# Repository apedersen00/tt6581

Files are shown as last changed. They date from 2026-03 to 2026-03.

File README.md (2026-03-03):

  

# TT6581

Inspired by the legendary MOS6581 Sound Interface Device (SID) chip used in retro computers such as the Commodore 64, the _Tiny Tapeout_ 6581 (TT6581) is a original digital interpretation supporting nearly the entire original MOS6581 feature set, implemented in 2x2 tiles for Tiny Tapeout.

For a detailed write-up, see the [project page](https://andreaspedersen.com/projects/tt6581/).

As a demonstration, here are two songs that **are produced by RTL testbenches**:

1. **Port of _Monty on the Run_ by Rob Hubbard** (`sim_tt6581_player.cpp`)

https://github.com/user-attachments/assets/aede3a49-307a-4b56-abea-9a842e0d1250

2. **10-second Nocturne demonstrating the filter** (`sim_tt6581.cpp`)

https://github.com/user-attachments/assets/fff6d938-7d75-444d-9261-1e6ea31e3630

## Features

- Full control through a Serial-Peripheral Interface (SPI).
- Three independently synthesized voices.
- Four supported waveform types (triangle, sawtooth, square and noise).
- Attack, decay, sustain, release (ADSR) envelope shaping.
- Chamberlin State-Variable Filter (SVF) for low-pass, high-pass, band-pass and band-reject.
- Second-order Delta-Sigma DAC.

## Architecture

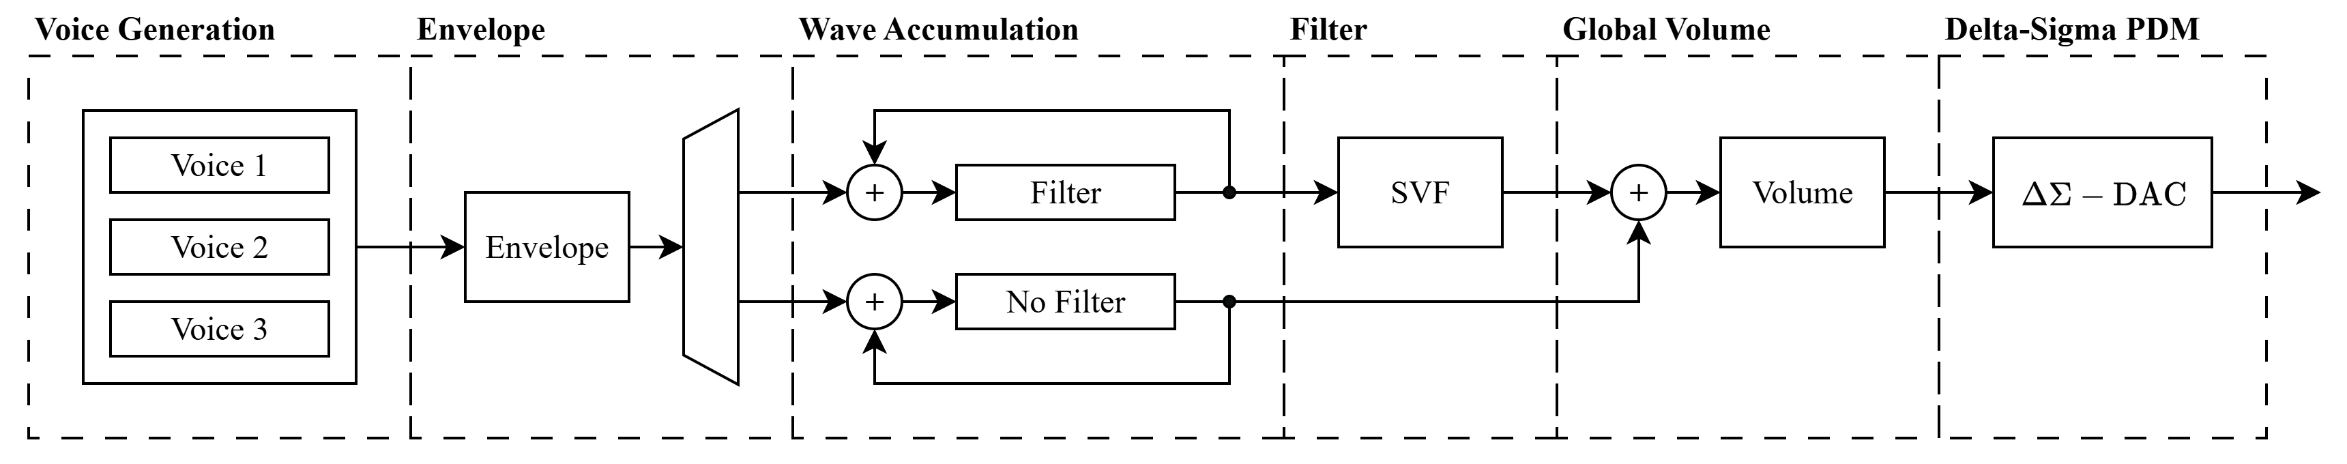
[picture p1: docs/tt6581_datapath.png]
TT6581 Architecture


The diagram above shows the datapath in the TT6581. A tick generator triggers the generation of a single audio sample at 50 kHz.

1. **Voice Generation:** One 10-bit voice at a time is generated. Internal phase registers keep track of each voice's state while inactive. The frequency and waveform type are set by the programmed values in the register file. Supported waveforms are triangle, sawtooth, pulse or noise.

2. **Envelope:** An ADSR envelope generator produces an 8-bit amplitude value per voice. The envelope is applied to each voice by multiplication.

3. **Wave Accumulation:** The three voices are accumulated (mixed) by addition. Depending on the filter enable bit of each voice, they are accumulated in one of two registers: one that will be passed through the SVF, or one that will bypass it.

4. **Filter:** A Chamberlin State-Variable Filter (SVF) processes the filter accumulator. It supports low-pass, high-pass, band-pass and band-reject modes with tuneable frequency cutoff and resonance (Q).

5. **Global Volume:** The SVF output is summed with the bypass accumulator. A global 8-bit volume is applied by multiplication resulting in the final mix.

6. **Delta-Sigma PDM:** An error-feedback Delta-Sigma modulator converts the final mix to 1-bit PDM output at 10 MHz (OSR = 200).

To fit the strict 2x2 tiles area requirement, the entire synthesis is time-multiplexed meaning most modules are _finite state machines_. A single 24x16 multiplier is shared for all modules. The 50 kHz sample tick wakes up a master controller (FSM) that then initiates the synthesis of a single sample.

## Pin Mapping

The TT6581 uses the bidirectional IO pins for SPI and a single dedicated output for the PDM audio signal. All dedicated inputs are unused.

| Pin | Direction | Function |
| --- | --- | --- |
| `uio[0]` | Input | SPI Chip Select (active low) |
| `uio[1]` | Input | SPI MOSI |
| `uio[2]` | Output | SPI MISO |
| `uio[3]` | Input | SPI SCLK |
| `uio[4:7]` | - | Unused |
| `uo[0]` | Output | PDM audio output |
| `uo[1:7]`  | - | Unused |
| `ui[0:7]`  | - | Unused |

The PDM output should be passed through a 4th order Bessel filter for the best reconstruction of the analog waveform.

## Quick Start

The TT6581 is programmed in much the same way as the original MOS6581. The register layout mirrors the original SID, three voice channels followed by filter and volume registers and the same ADSR, waveform selection and filter concepts apply. The main differences are:

- Registers are accessed through an SPI interface.
- The filter coefficients are pre-calculated and written directly as fixed-point values, rather than the raw 11-bit FC value used by the MOS6581.

Keeping the changes in mind, the original MOS6581 datasheet is a good reference for how to use the TT6581.

### SPI Protocol

The SPI interface uses CPOL=0, CPHA=0 (data sampled on the rising edge of SCLK). Each transaction is a 16-bit frame while CS is held low:

| Bit | 15 | 14:8 | 7:0 |
| ----- | --- | --- | --- |
| Field | R/W | Address \[6:0\] | Data \[7:0\] |

- **Bit 15** = `1` for write, `0` for read.
- **Bits 14:8** = 7-bit register address.
- **Bits 7:0** = write data.

Data is transmitted MSB first.

### Playing a tone

1. **Set volume:** Write `0xFF` to register `VOLUME` for max volume.
2. **Set frequency:** Compute the 16-bit frequency control word and write it to `FREQ_LO` / `FREQ_HI`.
3. **Set ADSR:** Write attack/decay to `AD` and sustain/release to `SR`.
4. **Select waveform and gate on:** Write the CONTROL register with the desired waveform bit and `GATE=1`.

For example, to play a 440 Hz sawtooth on Voice 0 with instant attack and full sustain:

```
SPI Write: addr=0x1A, data=0xFF    # Volume = max
SPI Write: addr=0x00, data=0x05    # FREQ_LO = 0x05  (FCW for 440 Hz = 0x1205)
SPI Write: addr=0x01, data=0x12    # FREQ_HI = 0x12
SPI Write: addr=0x05, data=0x00    # AD = 0x00 (attack=0, decay=0)
SPI Write: addr=0x06, data=0xF0    # SR = 0xF0 (sustain=15, release=0)
SPI Write: addr=0x04, data=0x21    # CONTROL = sawtooth + gate on
```

To release the note, write CONTROL again with `GATE=0`:

```
SPI Write: addr=0x04, data=0x20    # CONTROL = sawtooth + gate off
```

### Formulas

**Frequency Control Word (FCW):**

$$
FCW = \frac{f_{\text{desired}} \cdot 2^{19}}{F_s}
$$

where $F_s = 50$ kHz (sample rate). The 16-bit FCW is split across `FREQ_LO` (bits 7:0) and `FREQ_HI` (bits 15:8).

The maximum representable voice frequency is limited by the 16-bit FCW:

$$
f_{\max} = \frac{65535 \cdot F_s}{2^{19}} \approx 6250 \text{ Hz}
$$

**Filter Cutoff Coefficient** (Q1.15 signed):

$$
\text{FCC} = \left[ 2 \cdot \sin \left(\frac{\pi \cdot f_c}{F_s}\right) \cdot 32768 \right]
$$

where $f_c$ is the desired cutoff frequency in Hz. The 16-bit result is split across `F_LO` and `F_HI`.

**Filter Damping Coefficient** (Q4.12 signed):

$$
\text{FDC} = \left[ \frac{1}{Q} \cdot 4096 \right]
$$

where $Q$ is the desired resonance. The 16-bit result is split across `Q_LO` and `Q_HI`.

## Register Map

The TT6581 has a 7-bit address space and 26 8-bit registers. Three identical voice register groups are followed by a filter/volume group.

The full register map is described in `regs.yaml`.

### Voice Registers

Each voice occupies 7 consecutive 8-bit registers. Voice 0 starts at `0x00`, Voice 1 at `0x07`, and Voice 2 at `0x0E`.

| Offset | Name | Bits | Description |
| --- | --- | ---- | --- |
| 0x00 | FREQ_LO | 7:0  | Frequency control word - low byte  |
| 0x01 | FREQ_HI | 7:0  | Frequency control word - high byte |
| 0x02 | PW_LO | 7:0  | Pulse width - low byte |
| 0x03 | PW_HI | 3:0  | Pulse width - high byte |
| 0x04 | CONTROL | 7:0  | Waveform select and voice control  |
| 0x05 | AD | 7:0  | Attack (7:4) / Decay (3:0) |
| 0x06 | SR | 7:0  | Sustain (7:4) / Release (3:0) |

**CONTROL register bit fields:**

| Bit | Name | Description |
| --- | --- | --- |
| 7 | NOISE | Select noise waveform |
| 6 | PULSE | Select pulse (square) waveform |
| 5 | SAW | Select sawtooth waveform |
| 4 | TRI | Select triangle waveform |
| 3 | - | Reserved |
| 2 | RING_MOD | Enable ring modulation |
| 1 | SYNC | Enable oscillator sync |
| 0 | GATE | Gate (1 = attack, 0 = release) |

### Filter and Volume Registers

| Address | Name | Bits | Description |
| --- | --- | ---- | --- |
| 0x15 | F_LO | 7:0  | Filter cutoff coefficient - low byte |
| 0x16 | F_HI | 7:0  | Filter cutoff coefficient - high byte  |
| 0x17 | Q_LO | 7:0  | Filter damping coefficient - low byte  |
| 0x18 | Q_HI | 7:0  | Filter damping coefficient - high byte |
| 0x19 | EN_MODE | 5:0  | Filter enable and mode select |
| 0x1A | VOLUME  | 7:0  | Global volume (0x00–0xFF) |

**EN_MODE bit fields:**

| Bit | Name | Description |
| --- | --- | --- |
| 5 | FILT_V2 | Route Voice 2 through filter |
| 4 | FILT_V1 | Route Voice 1 through filter |
| 3 | FILT_V0 | Route Voice 0 through filter |
| 2:0 | MODE | Filter mode: `001`=LP, `010`=BP, `100`=HP, `101`=BR |

## Building and Testing

The project contains two separate testbench environments:

1. C++ testbenches for Verilator
2. CocoTB testbenches

The C++ Verilator testbenches are significantly faster and were the main tool for verification during development. The CocoTB testbenches were implemented as high-level verification that can also run on the synthesized gate-level netlist.

### Verilator

Verilator testbenches are stored in `sim/`:

```
sim
├── cpp         # C++ testbenches
├── logs        # Waveform files
├── tmp         # Temporary data files from the TBs
├── out         # Testbench results
├── scripts     # Python scripts for parsing TB intermediate files in out/
├── stimulus    # Stimulus file for tt6581_player TB
├── tb          # SystemVerilog wrappers for the testbenches
└── Makefile    # Makefile for running the testbenches
```

To run a testbench, simply run make and specify the simulation target:

```bash
make tt6581
make tt6581_player
make tt6581_bode
make svf
make spi
make mult
make envelope
make delta_sigma
```

A brief description of each testbench:

- **tt6581:** Plays a 10-second song. The Delta-Sigma PDM output is captured to a binary file. A Python script reads the PDM output and applies a 4th order Bessel filter and saves the output to a `.wav` file. Intended to demonstrate most of the TT6581's capabilities. Uses all three voices and the filter.

- **tt6581_player:** This testbench simulates and plays the entirety of _Monty on the Run_ by Rob Hubbard. Like **tt6581**, the PDM output is captured and a Python script reconstructs the audio by applying a 4th order Bessel filter. The song is played by reading the stimulus file `stimulus/Hubbard_Rob_Monty_on_the_Run_tt6581_stimulus.txt`. The stimulus was generated by running the assembly code for _Monty on the Run_ (from [this](https://github.com/realdmx/c64_6581_sid_players) repository) in a modified 6502 emulator that records all memory writes to the SID. The recorded memory writes were then translated to work on the TT6581.

- **tt6581_bode**: Simply plays a sine sweep and records the output. Produces a bode plot. Intended to check the frequency range.

- **svf:** Tests the Chamberlin SVF in all four supported modes. A sine sweep is used as the input. Produces four frequency response plots as the output.

- **mult:** Tests the 24x16 shift-add multiplier. Inputs N randomly generated operands and verifies the hardware result against software.

- **envelope:** Tests the envelope generator by inputting known ADSR values with a constant wave input. Plots the produced envelope.

- **delta_sigma:** Inputs a sine wave to the Delta-Sigma module and records the PDM output. A plot shows the time-domain reconstructed waveform and the output in the frequency domain.

### CocoTB

Currently has three testbenches. They are automatically run as a GitHub Action on push. When all three tests have completed, a summary is generated and stored. More importantly, these tests are also run on the synthesized gate-level netlist. To see the three tests and the summary, simply go to a successful `test` or `gl_test` run.

- [Latest test results](https://github.com/apedersen00/tt6581/actions/workflows/test.yaml?query=is%3Asuccess)
- [Latest gate-level test results](https://github.com/apedersen00/tt6581/actions/workflows/gds.yaml?query=is%3Asuccess)

## References

- **Musical Applications of Microprocessors:** Hal Chamberlin. Source for the State-Variable Filter (SVF).
- **Understanding Delta-Sigma Data Converters:** Richard Schreier, Gabor C. Temes. Source for the error-feedback Delta-Sigma modulator.

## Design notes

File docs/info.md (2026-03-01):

<!---

This file is used to generate your project datasheet. Please fill in the information below and delete any unused
sections.

You can also include images in this folder and reference them in the markdown. Each image must be less than
512 kb in size, and the combined size of all images must be less than 1 MB.
-->

## How it works

Inspired by the legendary MOS6581 Sound Interface Device (SID) chip used in retro computers such as the Commodore 64, the _Tiny Tapeout_ 6581 (TT6581) is a original digital interpretation supporting nearly the entire original MOS6581 feature set, implemented in 2x2 tiles for Tiny Tapeout.

All configuration is done via a 4-wire SPI interface, and the audio output is a 1-bit PDM signal at 10 MHz.

### Features

- Full control through a Serial-Peripheral Interface (SPI).
- Three independently synthesized voices.
- Four supported waveform types (triangle, sawtooth, square and noise).
- Attack, decay, sustain, release (ADSR) envelope shaping.
- Chamberlin State-Variable Filter (SVF) for low-pass, high-pass, band-pass and band-reject.
- Second-order Delta-Sigma DAC.

### Architecture

TT6581 Architecture

The diagram above shows the datapath in the TT6581. A tick generator triggers the generation of a single audio sample at 50 kHz.

1. **Voice Generation:** One 10-bit voice at a time is generated. Internal phase registers keep track of each voice's state while inactive. The frequency and waveform type are set by the programmed values in the register file. Supported waveforms are triangle, sawtooth, pulse or noise.

2. **Envelope:** An ADSR envelope generator produces an 8-bit amplitude value per voice. The envelope is applied to each voice by multiplication.

3. **Wave Accumulation:** The three voices are accumulated (mixed) by addition. Depending on the filter enable bit of each voice, they are accumulated in one of two registers: one that will be passed through the SVF, or one that will bypass it.

4. **Filter:** A Chamberlin State-Variable Filter (SVF) processes the filter accumulator. It supports low-pass, high-pass, band-pass and band-reject modes with tuneable frequency cutoff and resonance (Q).

5. **Global Volume:** The SVF output is summed with the bypass accumulator. A global 8-bit volume is applied by multiplication resulting in the final mix.

6. **Delta-Sigma PDM:** An error-feedback Delta-Sigma modulator converts the final mix to 1-bit PDM output at 10 MHz (OSR = 200).

To fit the strict 2x2 tiles area requirement, the entire synthesis is time-multiplexed meaning most modules are _finite state machines_. A single 24x16 multiplier is shared for all modules. The 50 kHz sample tick wakes up a master controller (FSM) that then initiates the synthesis of a single sample.

### Pin Mapping

The TT6581 uses the bidirectional IO pins for SPI and a single dedicated output for the PDM audio signal. All dedicated inputs are unused.

| Pin | Direction | Function |
| --- | --- | --- |
| `uio[0]` | Input | SPI Chip Select (active low) |
| `uio[1]` | Input | SPI MOSI |
| `uio[2]` | Output | SPI MISO |
| `uio[3]` | Input | SPI SCLK |
| `uio[4:7]` | - | Unused |
| `uo[0]` | Output | PDM audio output |
| `uo[1:7]`  | - | Unused |
| `ui[0:7]`  | - | Unused |

The PDM output should be passed through a 4th order Bessel filter for the best reconstruction of the analog waveform.

### Programming

The TT6581 is programmed in much the same way as the original MOS6581. The register layout mirrors the original SID, three voice channels followed by filter and volume registers and the same ADSR, waveform selection and filter concepts apply. The main differences are:

- Registers are accessed through an SPI interface.
- The filter coefficients are pre-calculated and written directly as fixed-point values, rather than the raw 11-bit FC value used by the MOS6581.

Keeping the changes in mind, the original MOS6581 datasheet is a good reference for how to use the TT6581.

### SPI Protocol

The SPI interface uses CPOL=0, CPHA=0 (data sampled on the rising edge of SCLK). Each transaction is a 16-bit frame while CS is held low:

| Bit | 15 | 14:8 | 7:0 |
| ----- | --- | --- | --- |
| Field | R/W | Address \[6:0\] | Data \[7:0\] |

- **Bit 15** = `1` for write, `0` for read.
- **Bits 14:8** = 7-bit register address.
- **Bits 7:0** = write data.

Data is transmitted MSB first.

### Playing a tone

1. **Set volume:** Write `0xFF` to register `VOLUME` for max volume.
2. **Set frequency:** Compute the 16-bit frequency control word and write it to `FREQ_LO` / `FREQ_HI`.
3. **Set ADSR:** Write attack/decay to `AD` and sustain/release to `SR`.
4. **Select waveform and gate on:** Write the CONTROL register with the desired waveform bit and `GATE=1`.

For example, to play a 440 Hz sawtooth on Voice 0 with instant attack and full sustain:

```
SPI Write: addr=0x1A, data=0xFF    # Volume = max
SPI Write: addr=0x00, data=0x05    # FREQ_LO = 0x05  (FCW for 440 Hz = 0x1205)
SPI Write: addr=0x01, data=0x12    # FREQ_HI = 0x12
SPI Write: addr=0x05, data=0x00    # AD = 0x00 (attack=0, decay=0)
SPI Write: addr=0x06, data=0xF0    # SR = 0xF0 (sustain=15, release=0)
SPI Write: addr=0x04, data=0x21    # CONTROL = sawtooth + gate on
```

To release the note, write CONTROL again with `GATE=0`:

```
SPI Write: addr=0x04, data=0x20    # CONTROL = sawtooth + gate off
```

### Formulas

**Frequency Control Word (FCW):**

$$
FCW = \frac{f_{\text{desired}} \times 2^{19}}{F_s}
$$

where $F_s = 50$ kHz (sample rate). The 16-bit FCW is split across `FREQ_LO` (bits 7:0) and `FREQ_HI` (bits 15:8).

The maximum representable voice frequency is limited by the 16-bit FCW:

$$
f_{\max} = \frac{65535 \times F_s}{2^{19}} \approx 6250 \text{ Hz}
$$

**Filter Cutoff Coefficient** (Q1.15 signed):

$$
\text{FCC} = \left[ 2 \cdot \sin \left( \frac{\pi \cdot f_c}{F_s} \right) \cdot 32768 \right]
$$

where $f_c$ is the desired cutoff frequency in Hz. The 16-bit result is split across `F_LO` and `F_HI`.

**Filter Damping Coefficient** (Q4.12 signed):

$$
\text{FDC} = \left[ \frac{1}{Q} \cdot 4096 \right]
$$

where $Q$ is the desired resonance. The 16-bit result is split across `Q_LO` and `Q_HI`.

### Register map summary

The TT6581 has a 7-bit address space and 26 8-bit registers. Three identical voice register groups are followed by a filter/volume group.

The full register map is described in `regs.yaml`.

#### Voice Registers

Each voice occupies 7 consecutive 8-bit registers. Voice 0 starts at `0x00`, Voice 1 at `0x07`, and Voice 2 at `0x0E`.

| Offset | Name | Bits | Description |
| --- | --- | ---- | --- |
| 0x00 | FREQ_LO | 7:0  | Frequency control word - low byte  |
| 0x01 | FREQ_HI | 7:0  | Frequency control word - high byte |
| 0x02 | PW_LO | 7:0  | Pulse width - low byte |
| 0x03 | PW_HI | 3:0  | Pulse width - high byte |
| 0x04 | CONTROL | 7:0  | Waveform select and voice control  |
| 0x05 | AD | 7:0  | Attack (7:4) / Decay (3:0) |
| 0x06 | SR | 7:0  | Sustain (7:4) / Release (3:0) |

**CONTROL register bit fields:**

| Bit | Name | Description |
| --- | --- | --- |
| 7 | NOISE | Select noise waveform |
| 6 | PULSE | Select pulse (square) waveform |
| 5 | SAW | Select sawtooth waveform |
| 4 | TRI | Select triangle waveform |
| 3 | - | Reserved |
| 2 | RING_MOD | Enable ring modulation |
| 1 | SYNC | Enable oscillator sync |
| 0 | GATE | Gate (1 = attack, 0 = release) |

#### Filter and Volume Registers

| Address | Name | Bits | Description |
| --- | --- | ---- | --- |
| 0x15 | F_LO | 7:0  | Filter cutoff coefficient - low byte |
| 0x16 | F_HI | 7:0  | Filter cutoff coefficient - high byte  |
| 0x17 | Q_LO | 7:0  | Filter damping coefficient - low byte  |
| 0x18 | Q_HI | 7:0  | Filter damping coefficient - high byte |
| 0x19 | EN_MODE | 5:0  | Filter enable and mode select |
| 0x1A | VOLUME  | 7:0  | Global volume (0x00–0xFF) |

**EN_MODE bit fields:**

| Bit | Name | Description |
| --- | --- | --- |
| 5 | FILT_V2 | Route Voice 2 through filter |
| 4 | FILT_V1 | Route Voice 1 through filter |
| 3 | FILT_V0 | Route Voice 0 through filter |
| 2:0 | MODE | Filter mode: `001`=LP, `010`=BP, `100`=HP, `101`=BR |

## How to test

1. Connect an SPI master to the bidirectional IO pins:
    - `uio[0]` = CS (active low)
    - `uio[1]` = MOSI
    - `uio[2]` = MISO
    - `uio[3]` = SCLK

2. Connect `uo[0]` (PDM output) through a low-pass reconstruction filter (e.g. 4th-order Bessel, cutoff ≈ 20 kHz) to an amplifier or speaker.

3. Program a voice. Minimal example for a 440 Hz sawtooth:
    - Write `0xFF` to `0x1A` (volume = max).
    - Write `0x05` to `0x00` and `0x12` to `0x01` (frequency control word for 440 Hz).
    - Write `0x00` to `0x05` (attack=0, decay=0) and `0xF0` to `0x06` (sustain=15, release=0).
    - Write `0x21` to `0x04` (sawtooth waveform + gate on).

4. A 440 Hz sawtooth tone _should_ be playing. Write `0x20` to `0x04` to release the note.

The project also includes a CocoTB test suite that runs automatically via GitHub Actions on both RTL and the synthesized gate-level netlist.

## External hardware

- SPI master.
- Low-pass 4th order reconstruction filter for the PDM output (Ideally Bessel).
- Audio amplifier and speaker/headphones.

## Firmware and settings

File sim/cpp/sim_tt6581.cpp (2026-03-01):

//-------------------------------------------------------------------------------------------------
//
//  File: sim_tt6581.cpp
//  Description: Verilator testbench for TT6581.
//               Plays a 10 second song utilizing most of the TT6581.
//
//  Author:
//    - Andreas Pedersen
//
//-------------------------------------------------------------------------------------------------

#include "sim_common.h"
#include "Vtb_tt6581.h"

#include <vector>
#include <algorithm>

// Notes
const double C2  = 65.41,  D2  = 73.42,  Eb2 = 77.78,  F2  = 87.31;
const double G2  = 98.00,  Ab2 = 103.83, Bb2 = 116.54, B2  = 123.47;
const double C3  = 130.81, D3  = 146.83, Eb3 = 155.56, F3  = 174.61;
const double G3  = 196.00, Ab3 = 207.65, Bb3 = 233.08, B3  = 246.94;
const double C4  = 261.63, D4  = 293.66, Eb4 = 311.13, F4  = 349.23;
const double G4  = 392.00, Ab4 = 415.30, Bb4 = 466.16, B4  = 493.88;
const double C5  = 523.25, D5  = 587.33, Eb5 = 622.25, G5  = 783.99;

enum class EventType { GATE_ON, GATE_OFF, FREQ_ONLY };

struct NoteEvent {
    uint64_t  sample;
    uint8_t   voice;
    double    freq;
    uint8_t   wave;
    EventType type;
};

struct FilterEvent {
    uint64_t sample;
    double   fc;
    double   q;
    uint8_t  en_mode;
};

void add_filter_event(std::vector<FilterEvent>& events, double time_s,
                      double fc, double q, uint8_t en_mode, int sr) {
    uint64_t s = (uint64_t)(time_s * sr);
    events.push_back({s, fc, q, en_mode});
}

// Add a note with automatic gate-off before the end (for envelope retrigger)
void add_note(std::vector<NoteEvent>& events, double time_s,
              uint8_t voice, double freq, double dur_s, uint8_t wave,
              int sr, double release_gap = 0.03) {
    uint64_t on  = (uint64_t)(time_s * sr);
    uint64_t off = (uint64_t)((time_s + dur_s - release_gap) * sr);
    events.push_back({on,  voice, freq, wave, EventType::GATE_ON});
    events.push_back({off, voice, 0,    wave, EventType::GATE_OFF});
}

// Add arpeggio cycling through 3 notes (gate stays on, only freq changes)
void add_arpeggio(std::vector<NoteEvent>& events,
                  double start_s, double end_s,
                  uint8_t voice, uint8_t wave,
                  double f1, double f2, double f3, int sr) {
    const double step = 0.125;
    double freqs[] = {f1, f2, f3};
    // Initial gate on
    events.push_back({(uint64_t)(start_s * sr), voice, f1, wave, EventType::GATE_ON});
    double t = start_s + step;
    int idx = 1;
    while (t < end_s - 0.05) {
        events.push_back({(uint64_t)(t * sr), voice, freqs[idx % 3], wave, EventType::FREQ_ONLY});
        t += step;
        idx++;
    }
    // Gate off at end
    events.push_back({(uint64_t)((end_s - 0.02) * sr), voice, 0, wave, EventType::GATE_OFF});
}

int main(int argc, char** argv) {
    Verilated::mkdir("logs");
    const std::unique_ptr<VerilatedContext> contextp{new VerilatedContext};
    contextp->commandArgs(argc, argv);
    contextp->traceEverOn(false);
    const std::unique_ptr<Vtb_tt6581> top{new Vtb_tt6581{contextp.get(), "TOP"}};

    PdmCapture pdm;
    uint64_t tick_count = 0;

    auto sys_tick = [&]() {
        tick(contextp, top);
        tick_count++;
        if (pdm.active && (tick_count % CYCLES_PER_DAC == 0)) {
            pdm.capture(top->wave_o);
        }
    };

    auto sys_tick_batch = [&](uint64_t n) {
        for (uint64_t i = 0; i < n; i++) sys_tick();
    };

    pdm.open("tmp/pdm_out.bin");

    // Initial pin state
    top->clk_i  = 0;
    top->rst_ni = 0;
    top->sclk_i = 0;
    top->cs_i   = 1;
    top->mosi_i = 0;

    const float  DURATION = 10.0;
    const double Q = 0.5;   // quarter note at 120 BPM
    const double E = 0.25;  // eighth note
    const double H = 1.0;   // half note

    uint64_t max_samples   = DURATION * SAMPLE_RATE_HZ;
    uint64_t total_samples = 0;

    std::cout << "[TB] TT6581 Test Song" << std::endl;
    std::cout << "[TB] Duration: " << DURATION << "s (" << max_samples << " samples)" << std::endl;
    std::cout << "[TB] PDM output: 10 MHz, 1-bit, packed binary" << std::endl;

    // Reset
    for (int i = 0; i < 5; i++) sys_tick();
    top->rst_ni = 1;
    for (int i = 0; i < 5; i++) sys_tick();

    // Voice 1: Lead (Pulse 25% duty cycle)
    spi_write(top, sys_tick, V1_BASE + REG_PW_LO, 0x00);
    spi_write(top, sys_tick, V1_BASE + REG_PW_HI, 0x04);  // PW = 0x400 = 25%
    set_adsr(top, sys_tick, V1_BASE, 2, 6, 10, 5);

    // Voice 2: Bass (Sawtooth)
    set_adsr(top, sys_tick, V2_BASE, 0, 5, 10, 3);

    // Voice 3: Arpeggio (Triangle)
    set_adsr(top, sys_tick, V3_BASE, 0, 2, 15, 3);

    // Volume
    spi_write(top, sys_tick, FILT_BASE + REG_VOLUME, 0xFF);

    // Initial filter: warm low-pass, all voices routed, Butterworth Q
    const uint8_t FILT_ALL_LP = FILT_V1 | FILT_V2 | FILT_V3 | FILT_LP;
    const uint8_t FILT_ALL_HP = FILT_V1 | FILT_V2 | FILT_V3 | FILT_HP;
    set_filter(top, sys_tick, 600.0, 0.707, FILT_ALL_LP);

    std::vector<NoteEvent> song;

    // Voice 1
    add_note(song, 1.00, V1_BASE, G4,  E, WAVE_PULSE, SAMPLE_RATE_HZ);
    add_note(song, 1.25, V1_BASE, Eb4, E, WAVE_PULSE, SAMPLE_RATE_HZ);
    add_note(song, 1.50, V1_BASE, C4,  Q, WAVE_PULSE, SAMPLE_RATE_HZ);

    add_note(song, 2.00, V1_BASE, F4,  E, WAVE_PULSE, SAMPLE_RATE_HZ);
    add_note(song, 2.25, V1_BASE, Ab4, E, WAVE_PULSE, SAMPLE_RATE_HZ);
    add_note(song, 2.50, V1_BASE, G4,  Q, WAVE_PULSE, SAMPLE_RATE_HZ);
    add_note(song, 3.00, V1_BASE, Eb4, E, WAVE_PULSE, SAMPLE_RATE_HZ);
    add_note(song, 3.25, V1_BASE, D4,  E, WAVE_PULSE, SAMPLE_RATE_HZ);
    add_note(song, 3.50, V1_BASE, C4,  Q, WAVE_PULSE, SAMPLE_RATE_HZ);

    add_note(song, 4.00, V1_BASE, Eb4, E, WAVE_PULSE, SAMPLE_RATE_HZ);
    add_note(song, 4.25, V1_BASE, G4,  E, WAVE_PULSE, SAMPLE_RATE_HZ);
    add_note(song, 4.50, V1_BASE, Ab4, Q, WAVE_PULSE, SAMPLE_RATE_HZ);
    add_note(song, 5.00, V1_BASE, Bb4, E, WAVE_PULSE, SAMPLE_RATE_HZ);
    add_note(song, 5.25, V1_BASE, Ab4, E, WAVE_PULSE, SAMPLE_RATE_HZ);
    add_note(song, 5.50, V1_BASE, G4,  Q, WAVE_PULSE, SAMPLE_RATE_HZ);

    add_note(song, 6.00, V1_BASE, F4,  E, WAVE_PULSE, SAMPLE_RATE_HZ);
    add_note(song, 6.25, V1_BASE, Ab4, E, WAVE_PULSE, SAMPLE_RATE_HZ);
    add_note(song, 6.50, V1_BASE, G4,  Q, WAVE_PULSE, SAMPLE_RATE_HZ);
    add_note(song, 7.00, V1_BASE, F4,  E, WAVE_PULSE, SAMPLE_RATE_HZ);
    add_note(song, 7.25, V1_BASE, Eb4, E, WAVE_PULSE, SAMPLE_RATE_HZ);
    add_note(song, 7.50, V1_BASE, D4,  Q, WAVE_PULSE, SAMPLE_RATE_HZ);

    add_note(song, 8.00, V1_BASE, C5,  H, WAVE_PULSE, SAMPLE_RATE_HZ);
    add_note(song, 9.00, V1_BASE, G4,  Q, WAVE_PULSE, SAMPLE_RATE_HZ);
    add_note(song, 9.50, V1_BASE, C4,  Q, WAVE_PULSE, SAMPLE_RATE_HZ, 0.15);

    // Voice 2
    add_note(song, 0.00, V2_BASE, C2,  Q, WAVE_SAW, SAMPLE_RATE_HZ);
    add_note(song, 0.50, V2_BASE, G2,  Q, WAVE_SAW, SAMPLE_RATE_HZ);
    add_note(song, 1.00, V2_BASE, C2,  Q, WAVE_SAW, SAMPLE_RATE_HZ);
    add_note(song, 1.50, V2_BASE, G2,  Q, WAVE_SAW, SAMPLE_RATE_HZ);

    add_note(song, 2.00, V2_BASE, F2,  Q, WAVE_SAW, SAMPLE_RATE_HZ);
    add_note(song, 2.50, V2_BASE, C3,  Q, WAVE_SAW, SAMPLE_RATE_HZ);
    add_note(song, 3.00, V2_BASE, G2,  Q, WAVE_SAW, SAMPLE_RATE_HZ);
    add_note(song, 3.50, V2_BASE, D3,  Q, WAVE_SAW, SAMPLE_RATE_HZ);

    add_note(song, 4.00, V2_BASE, Ab2, Q, WAVE_SAW, SAMPLE_RATE_HZ);
    add_note(song, 4.50, V2_BASE, Eb3, Q, WAVE_SAW, SAMPLE_RATE_HZ);
    add_note(song, 5.00, V2_BASE, Bb2, Q, WAVE_SAW, SAMPLE_RATE_HZ);
    add_note(song, 5.50, V2_BASE, F3,  Q, WAVE_SAW, SAMPLE_RATE_HZ);

    add_note(song, 6.00, V2_BASE, F2,  Q, WAVE_SAW, SAMPLE_RATE_HZ);
    add_note(song, 6.50, V2_BASE, C3,  Q, WAVE_SAW, SAMPLE_RATE_HZ);
    add_note(song, 7.00, V2_BASE, G2,  Q, WAVE_SAW, SAMPLE_RATE_HZ);
    add_note(song, 7.50, V2_BASE, D3,  Q, WAVE_SAW, SAMPLE_RATE_HZ);

    add_note(song, 8.00, V2_BASE, C2,  Q, WAVE_SAW, SAMPLE_RATE_HZ);
    add_note(song, 8.50, V2_BASE, G2,  Q, WAVE_SAW, SAMPLE_RATE_HZ);
    add_note(song, 9.00, V2_BASE, C3,  Q, WAVE_SAW, SAMPLE_RATE_HZ, 0.15);

    // Voice 3
    add_arpeggio(song, 0.0, 2.0, V3_BASE, WAVE_TRI, C4, Eb4, G4, SAMPLE_RATE_HZ);

    add_arpeggio(song, 2.0, 3.0, V3_BASE, WAVE_TRI, F3, Ab3, C4, SAMPLE_RATE_HZ);
    add_arpeggio(song, 3.0, 4.0, V3_BASE, WAVE_TRI, G3, B3,  D4, SAMPLE_RATE_HZ);

    add_arpeggio(song, 4.0, 5.0, V3_BASE, WAVE_TRI, Ab3, C4, Eb4, SAMPLE_RATE_HZ);
    add_arpeggio(song, 5.0, 6.0, V3_BASE, WAVE_TRI, Bb3, D4, F4,  SAMPLE_RATE_HZ);

    add_arpeggio(song, 6.0, 7.0, V3_BASE, WAVE_TRI, F3, Ab3, C4, SAMPLE_RATE_HZ);
    add_arpeggio(song, 7.0, 8.0, V3_BASE, WAVE_TRI, G3, B3,  D4, SAMPLE_RATE_HZ);

    add_arpeggio(song, 8.0, 9.5, V3_BASE, WAVE_TRI, C4, Eb4, G4, SAMPLE_RATE_HZ);

    // Filter events
    std::vector<FilterEvent> filter_song;

    // Low pass sweep in the beginning
    add_filter_event(filter_song, 0.00, 600.0,  1.0,   FILT_ALL_LP, SAMPLE_RATE_HZ);
    add_filter_event(filter_song, 0.50, 800.0,  1.0,   FILT_ALL_LP, SAMPLE_RATE_HZ);
    add_filter_event(filter_song, 1.00, 1200.0, 0.9,   FILT_ALL_LP, SAMPLE_RATE_HZ);
    add_filter_event(filter_song, 1.50, 1500.0, 0.8,   FILT_ALL_LP, SAMPLE_RATE_HZ);

    add_filter_event(filter_song, 2.00, 2000.0, 1.0,   FILT_ALL_LP, SAMPLE_RATE_HZ);
    add_filter_event(filter_song, 2.50, 2200.0, 1.2,   FILT_ALL_LP, SAMPLE_RATE_HZ);
    add_filter_event(filter_song, 3.00, 2500.0, 1.5,   FILT_ALL_LP, SAMPLE_RATE_HZ);
    add_filter_event(filter_song, 3.50, 2800.0, 1.2,   FILT_ALL_LP, SAMPLE_RATE_HZ);

    add_filter_event(filter_song, 4.00, 3500.0, 2.0,   FILT_ALL_LP, SAMPLE_RATE_HZ);
    add_filter_event(filter_song, 4.50, 4000.0, 2.5,   FILT_ALL_LP, SAMPLE_RATE_HZ);
    add_filter_event(filter_song, 5.00, 5000.0, 2.0,   FILT_ALL_LP, SAMPLE_RATE_HZ);
    add_filter_event(filter_song, 6.00, 8000.0, 1.2,   FILT_ALL_LP, SAMPLE_RATE_HZ);

    // High pass end
    add_filter_event(filter_song, 9.00, 100.0,   0.707, FILT_ALL_HP, SAMPLE_RATE_HZ);
    add_filter_event(filter_song, 9.50, 4000.0, 1.5,   FILT_ALL_HP, SAMPLE_RATE_HZ);

    std::sort(filter_song.begin(), filter_song.end(),
        [](const FilterEvent& a, const FilterEvent& b) { return a.sample < b.sample; });

    std::sort(song.begin(), song.end(),
        [](const NoteEvent& a, const NoteEvent& b) { return a.sample < b.sample; });

    tick_count = 0;
    pdm.active = true;

    size_t event_idx = 0;
    size_t filt_idx  = 0;

    while (total_samples < max_samples) {
        while (event_idx < song.size() && song[event_idx].sample <= total_samples) {
            auto& ev = song[event_idx];
            switch (ev.type) {
                case EventType::GATE_ON:
                    set_voice_freq(top, sys_tick, ev.voice, ev.freq);
                    set_control(top, sys_tick, ev.voice, ev.wave, true);
                    break;
                case EventType::GATE_OFF:
                    set_control(top, sys_tick, ev.voice, ev.wave, false);
                    break;
                case EventType::FREQ_ONLY:
                    set_voice_freq(top, sys_tick, ev.voice, ev.freq);
                    break;
            }
            event_idx++;
        }

        while (filt_idx < filter_song.size() && filter_song[filt_idx].sample <= total_samples) {
            auto& fe = filter_song[filt_idx];
            set_filter(top, sys_tick, fe.fc, fe.q, fe.en_mode);
            filt_idx++;
        }

        sys_tick_batch(CYCLES_PER_SAMPLE);
        total_samples++;

        if (total_samples % SAMPLE_RATE_HZ == 0) {
            std::cout << "[TB] Time: " << (total_samples / SAMPLE_RATE_HZ)
                      << "s / " << (int)DURATION << "s" << std::endl;
        }
    }

    pdm.flush();
    top->final();

    std::cout << "[TB] PDM samples captured: " << pdm.total
              << " (" << (double)pdm.total / DAC_RATE_HZ << "s at "
              << DAC_RATE_HZ / 1000000 << " MHz)" << std::endl;
    return 0;
}

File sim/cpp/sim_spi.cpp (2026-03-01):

//-------------------------------------------------------------------------------------------------
//
//  File: sim_spi.cpp
//  Description: Verilator testbench for register SPI interface.
//               Reads and writes test values and checks the reg_file interface.
//
//  Author:
//    - Andreas Pedersen
//
//-------------------------------------------------------------------------------------------------

#include "sim_common.h"
#include "Vtb_spi.h"

const int SPI_CLK_DIV = 20;  // SPI clock = SysClk / 20 = 2.5 MHz

uint8_t spi_bit(const std::unique_ptr<VerilatedContext>& ctx,
                const std::unique_ptr<Vtb_spi>& top,
                uint8_t bit_out) {
    uint8_t bit_in = 0;
    top->mosi_i = bit_out & 1;

    for (int i = 0; i < SPI_CLK_DIV / 2; i++) tick(ctx, top);

    top->sclk_i = 1;

    for (int i = 0; i < SPI_CLK_DIV / 2; i++) tick(ctx, top);

    top->sclk_i = 0;
    bit_in = top->miso_o;

    return bit_in;
}

uint8_t spi_byte(const std::unique_ptr<VerilatedContext>& ctx,
                 const std::unique_ptr<Vtb_spi>& top,
                 uint8_t data_out) {
    uint8_t data_in = 0;
    // MSB First
    for (int i = 7; i >= 0; i--) {
        uint8_t bit_val = (data_out >> i) & 1;
        uint8_t miso_bit = spi_bit(ctx, top, bit_val);
        if (miso_bit) {
            data_in |= (1 << i);
        }
    }
    return data_in;
}

void check_write(const std::unique_ptr<VerilatedContext>& ctx,
                 const std::unique_ptr<Vtb_spi>& top,
                 uint8_t addr, uint8_t data) {
    std::cout << "[Write] Addr: 0x" << std::hex << (int)addr
              << " Data: 0x" << (int)data << std::dec << " ... ";

    top->cs_i = 0;

    uint8_t cmd = 0x80 | (addr & 0x7F);
    spi_byte(ctx, top, cmd);
    spi_byte(ctx, top, data);

    for (int i = 0; i < 5; i++) tick(ctx, top);
    top->cs_i = 1;
    for (int i = 0; i < 5; i++) tick(ctx, top);

    if (top->reg_addr_o == addr && top->reg_wdata_o == data) {
        std::cout << "PASS" << std::endl;
    } else {
        std::cout << "FAIL (Got Addr: " << (int)top->reg_addr_o
                  << " Data: " << (int)top->reg_wdata_o << ")" << std::endl;
    }
}

void check_read(const std::unique_ptr<VerilatedContext>& ctx,
                const std::unique_ptr<Vtb_spi>& top,
                uint8_t addr, uint8_t expected_val) {
    std::cout << "[Read ] Addr: 0x" << std::hex << (int)addr << std::dec << " ... ";

    top->reg_rdata_i = expected_val;
    top->cs_i = 0;

    uint8_t cmd = 0x00 | (addr & 0x7F);
    spi_byte(ctx, top, cmd);

    uint8_t result = spi_byte(ctx, top, 0x00);

    for (int i = 0; i < 5; i++) tick(ctx, top);
    top->cs_i = 1;
    for (int i = 0; i < 5; i++) tick(ctx, top);

    if (result == expected_val) {
        std::cout << "PASS" << std::endl;
    } else {
        std::cout << "FAIL (Expected: " << (int)expected_val
                  << " Got: " << (int)result << ")" << std::endl;
    }
}

int main(int argc, char** argv) {
    Verilated::mkdir("logs");
    const std::unique_ptr<VerilatedContext> contextp{new VerilatedContext};
    contextp->commandArgs(argc, argv);
    contextp->traceEverOn(false);
    const std::unique_ptr<Vtb_spi> top{new Vtb_spi{contextp.get(), "TOP"}};

    // Initial pin state
    top->clk_i       = 0;
    top->rst_ni      = 0;
    top->sclk_i      = 0;
    top->cs_i        = 1;
    top->mosi_i      = 0;
    top->reg_rdata_i = 0;

    std::cout << "[TB] SPI Interface Testbench" << std::endl;

    // Reset
    for (int i = 0; i < 5; i++) tick(contextp, top);
    top->rst_ni = 1;
    for (int i = 0; i < 5; i++) tick(contextp, top);

    check_write(contextp, top, 0x02, 0xFF);
    check_write(contextp, top, 0x05, 0xAA);
    check_read(contextp, top, 0x02, 0x55);
    check_read(contextp, top, 0x05, 0x99);

    for (int i = 0; i < 50; i++) tick(contextp, top);

    top->final();

    std::cout << "[TB] Simulation finished." << std::endl;
    return 0;
}

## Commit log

2026-03-02 add filter design notebook
2026-03-05 add kicad project
    [power.kicad_sch, tt6581.kicad_pcb, tt6581.kicad_sch]
